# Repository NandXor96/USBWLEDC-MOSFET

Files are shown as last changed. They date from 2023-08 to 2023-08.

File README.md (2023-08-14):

# USBWLEDC MOSFET
USB Sound Reactive WLED Controller with MOSFET

## Features

- USB-C for flashing and power (max. 3A)
- Small size
- Cheap components
- MOSFET as "Relay"
- ICS-43434 MEMS Microphone (optional)
- Solder Pads instead of Screw Terminal Blocks

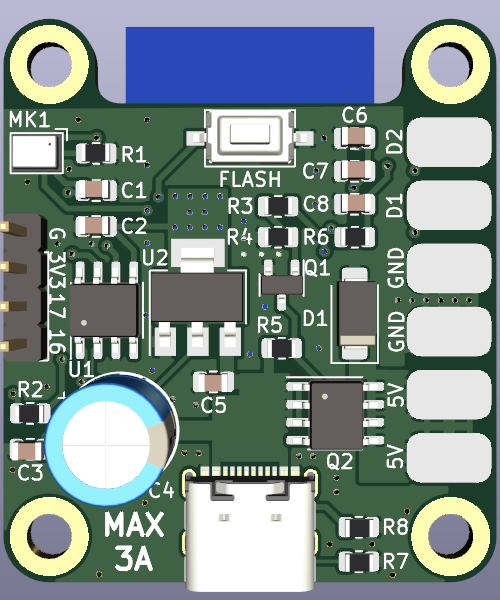
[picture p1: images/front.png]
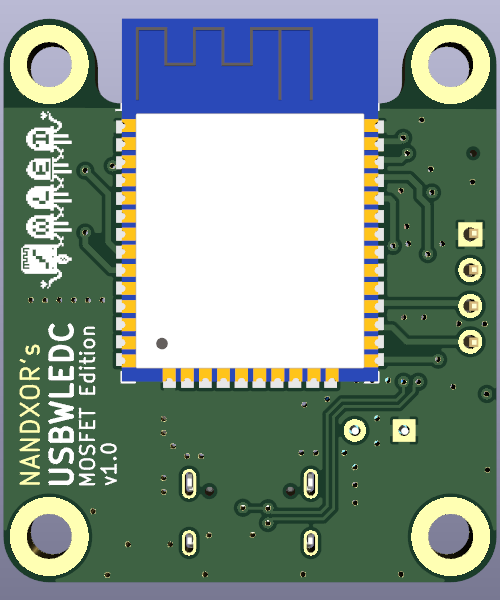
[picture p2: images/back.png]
 

## BOM

|Designator |Part |Quantity|Value |LCSC Part #| Mouser Part # |
|---|---|---|---|---|---|
|C1*, C2, C6 |0805 MLCC |3 |100nF 50V |C49678 ||
|C3, C5 |0805 MLCC |2 |22uF 25V |C45783 ||
|C4 |D8.0mm P3.50mm ELKO |1 |330uF 25V | ||
|C7 |0805 MLCC |1 |10uF 25V |C15850 ||
|C8 |0805 MLCC |1 |1uF 50V |C28323 ||
|D1 |Schottky Diode |1 |SS14 |C2480 ||
|J10 |USB-C Receptacle |1 |USB_C_Receptacle_USB2.0|C2988369 ||
|MK1* |InvenSense_ICS-43434 MEMS Microphone |1 |ICS-43434 | |410-ICS-43434|
|Q1 |N-Channel MOSFET |1 |IRLML6244 |C143946 ||
|Q2 |P-Channel MOSFET |1 |IRF7410TRPBF |C148144 ||
|R1* |0805 Resistor |1 |100k |C149504 ||
|R2, R4, R5, R6|0805 Resistor |4 |10k |C17414 ||
|R3 |0805 Resistor |1 |330R |C17630 ||
|R7, R8 |0805 Resistor |2 |5.1k |C27834 ||
|SW1 |Tactile Switch 6x3.5mm |1 |SWITCH |C3726366 ||
|U1 |USB-UART IC CH340N |1 |CH340N |C2977777 ||
|U2 |3.3V LDO AMS1117-3.3 |1 |AMS1117-3.3 |C6186 ||
|U3 |ESP32-WROOM-32 D or E |1 |ESP32-WROOM-32 |C701341 |356-ESP32WRM32E132PH|

\* You can build it without the microphone. Then you don't need R1, C1 and MK1.

## Assembly

To assemble the PCB, I recommend using a hot plate or soldering oven for the upper side, and hand-soldering for the ESP32 on the back.
**Preheat** the PCB before soldering anything by hand and use a **powerful soldering iron**!  

## Disclaimer

The circuit board provided on this GitHub repository is offered "as is," without any warranties or guarantees of any kind. By accessing and utilizing this circuit board, you acknowledge and agree that you do so at your own risk.

The creator and contributor of this repository, shall not be held responsible or liable for any damages, losses, or injuries that may occur as a result of building and / or using this circuit board. This includes but is not limited to any direct, indirect, consequential, or incidental damages.

Electricity is dangerous. Only attempt this project if you know what you're doing.

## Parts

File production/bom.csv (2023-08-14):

Designator | Footprint | Quantity | Value | LCSC Part #
C1, C2, C6 | 0805 | 3 | 100nF | C49678
C3, C5 | 0805 | 2 | 22uF | C45783
C4 | CP_Radial_D8.0mm_P3.50mm | 1 | 330uF
C7 | 0805 | 1 | 10uF | C15850
C8 | 0805 | 1 | 1uF | C28323
D1 | D_SMA | 1 | SS14 | C2480
H1, H2, H3, H4 | MountingHole_3.2mm_M3_DIN965_Pad_TopBottom | 4 | MountingHole
J1, J4 | SolderWirePad_1x01_SMD_3x6mm | 2 | 5V OUT PAD
J10 | USB_C_Receptacle_G-Switch_GT-USB-7010ASV | 1 | USB_C_Receptacle_USB2.0 | C2988369
J2 | SolderWirePad_1x01_SMD_3x6mm | 1 | D1 PAD
J3, J6 | SolderWirePad_1x01_SMD_3x6mm | 2 | GND PAD
J5 | SolderWirePad_1x01_SMD_3x6mm | 1 | D2 PAD
J7 | PinHeader_1x04_P2.54mm_Vertical | 1 | Conn_01x04_Pin
MK1 | InvenSense_ICS-43434-6_3.5x2.65mm | 1 | ICS-43434
Q1 | SOT-23-3 | 1 | IRLML6244 | C143946
Q2 | SO-8_3.9x4.9mm_P1.27mm | 1 | IRF7410TRPBF | C148144
R1 | 0805 | 1 | 100k | C149504
R2, R4, R5, R6 | 0805 | 4 | 10k | C17414
R3 | 0805 | 1 | 330R | C17630
R7, R8 | 0805 | 2 | 5.1k | C27834
SW1 | SW_Tactile_SPST_NO_Straight_CK_PTS636Sx25SMTRLFS | 1 | FLASH_SW | C3726366
U1 | SOP-8_3.9x4.9mm_P1.27mm | 1 | CH340N | C2977777
U2 | SOT-223-3_TabPin2 | 1 | AMS1117-3.3 | C6186
U3 | ESP32-WROOM-32 | 1 | ESP32-WROOM-32 | C701341

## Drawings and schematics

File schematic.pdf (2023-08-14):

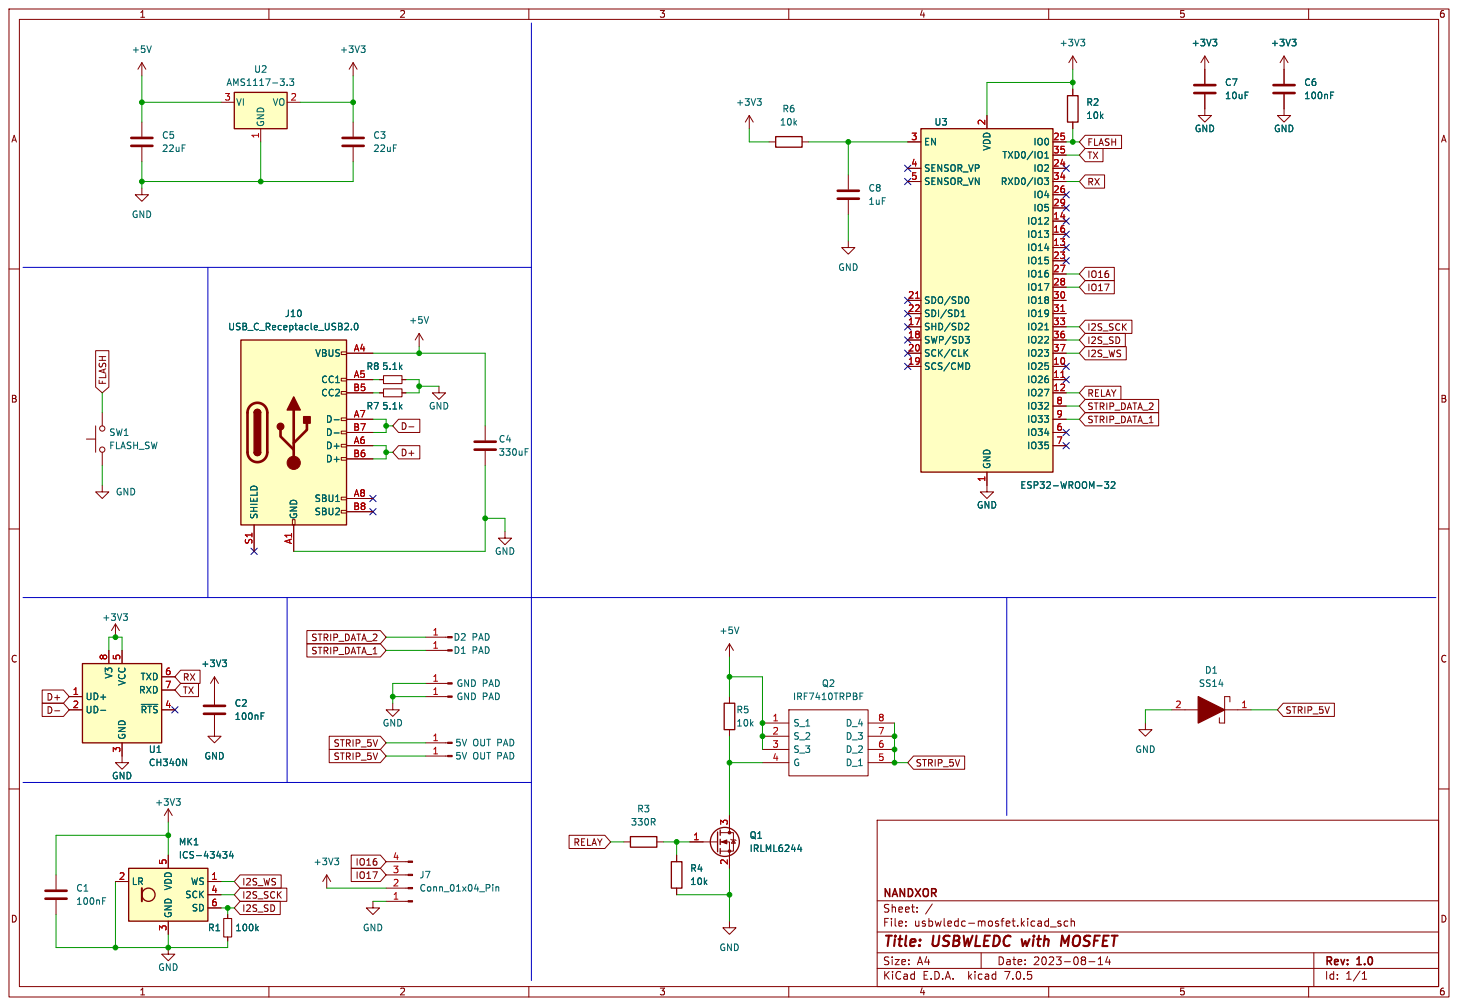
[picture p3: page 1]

File: usbwledc-mosfet.kicad_sch Sheet: / NANDXOR

Id: 1/1 Title: USBWLEDC with MOSFET

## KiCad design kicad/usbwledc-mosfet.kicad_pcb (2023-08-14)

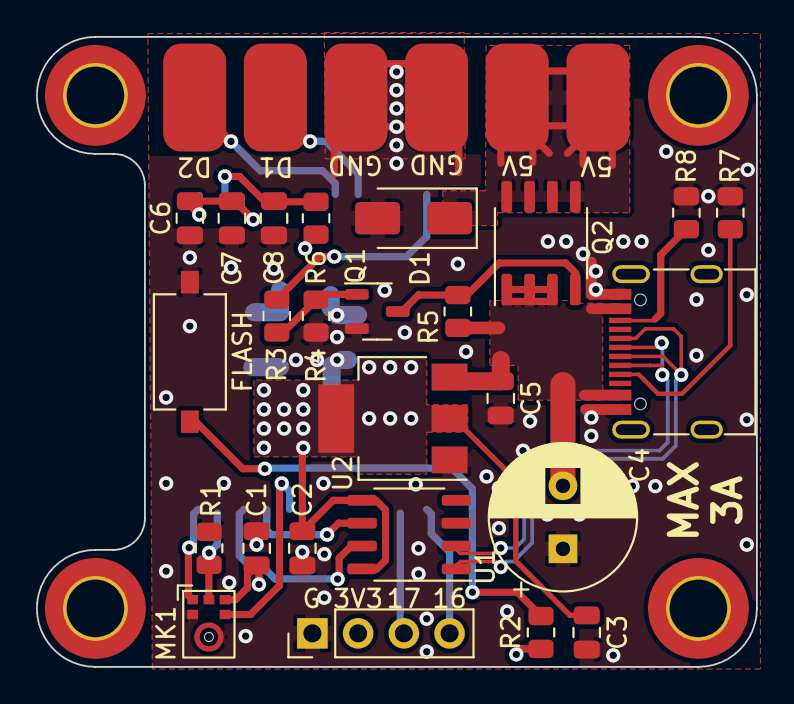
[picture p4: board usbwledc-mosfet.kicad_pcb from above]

Board: 4 copper layers, 40.0 x 35.0 mm, 36 parts (1 on the bottom side), 22 nets.

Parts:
C1, C2, C6: 100nF; C_0805_2012Metric
C3, C5: 22uF; C_0805_2012Metric
C4: 330uF; CP_Radial_D8.0mm_P3.50mm
C7: 10uF; C_0805_2012Metric
C8: 1uF; C_0805_2012Metric
D1: SS14; D_SMA
H1, H2, H3, H4: MountingHole; MountingHole_3.2mm_M3_DIN965_Pad_TopBottom
J1, J4: 5V OUT PAD; SolderWirePad_1x01_SMD_3x6mm
J2: D1 PAD; SolderWirePad_1x01_SMD_3x6mm
J3, J6: GND PAD; SolderWirePad_1x01_SMD_3x6mm
J5: D2 PAD; SolderWirePad_1x01_SMD_3x6mm
J7: Conn_01x04_Pin; PinHeader_1x04_P2.54mm_Vertical
J10: USB_C_Receptacle_USB2.0; USB_C_Receptacle_G-Switch_GT-USB-7010ASV
MK1: ICS-43434; InvenSense_ICS-43434-6_3.5x2.65mm
Q1: IRLML6244; SOT-23-3
Q2: IRF7410TRPBF; SO-8_3.9x4.9mm_P1.27mm
R1: 100k; R_0805_2012Metric
R2, R4, R5, R6: 10k; R_0805_2012Metric
R3: 330R; R_0805_2012Metric
R7, R8: 5.1k; R_0805_2012Metric
SW1: FLASH_SW; SW_Tactile_SPST_NO_Straight_CK_PTS636Sx25SMTRLFS
U1: CH340N; SOP-8_3.9x4.9mm_P1.27mm
U2: AMS1117-3.3; SOT-223-3_TabPin2
U3: ESP32-WROOM-32

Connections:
+3V3: C1.1, C2.2, C3.1, C6.2, C7.1, J7.2, MK1.5 (VDD), R2.1, R6.1, U1.5 (VCC), U1.8 (V3), U2.2 (VO), U3.2 (VDD)
+5V: C4.2, C5.1, J10.A4 (VBUS), J10.A9 (VBUS), J10.B4 (VBUS), J10.B9 (VBUS), Q2.1 (S_1), Q2.2 (S_2), Q2.3 (S_3), R5.1, U2.3 (VI)
D+: J10.A6 (D+), J10.B6 (D+), U1.1 (UD+)
D-: J10.A7 (D-), J10.B7 (D-), U1.2 (UD-)
FLASH: R2.2, SW1.2, U3.25 (IO0)
GND: C1.2, C2.1, C3.2, C4.1, C5.2, C6.1, C7.2, C8.2, D1.2, J3.1, J6.1, J7.1, J10.A1 (GND), J10.A12 (GND), J10.B1 (GND), J10.B12 (GND), MK1.2 (LR), MK1.3 (GND), Q1.2 (S), R1.1, R4.2, R7.2, R8.2, SW1.1, U1.3 (GND), U2.1 (GND), U3.1 (GND), U3.15 (GND), U3.38 (GND), U3.39 (GND)
I2S_SCK: MK1.4 (SCK), U3.33 (IO21)
I2S_SD: MK1.6 (SD), R1.2, U3.36 (IO22)
I2S_WS: MK1.1 (WS), U3.37 (IO23)
IO16: J7.4, U3.27 (IO16)
IO17: J7.3, U3.28 (IO17)
unnamed: J10.A5 (CC1), R7.1
unnamed: J10.B5 (CC2), R8.1
unnamed: Q1.3 (D), Q2.4 (G), R5.2
unnamed: Q1.1 (G), R3.2, R4.1
unnamed: C8.1, R6.2, U3.3 (EN)
RELAY: R3.1, U3.12 (IO27)
RX: U1.6 (TXD), U3.34 (RXD0/IO3)
STRIP_5V: D1.1, J1.1, J4.1, Q2.5 (D_1), Q2.6 (D_2), Q2.7 (D_3), Q2.8 (D_4)
STRIP_DATA_1: J2.1, U3.9 (IO33)
STRIP_DATA_2: J5.1, U3.8 (IO32)
TX: U1.7 (RXD), U3.35 (TXD0/IO1)
